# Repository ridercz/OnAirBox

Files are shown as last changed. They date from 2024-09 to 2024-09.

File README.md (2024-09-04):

# OnAirBox

ON-AIR indicator light controlled via MQTT, based on ESP32. In a home with two cats, two children and one wolfdig it's hard to get quiet to shoot video. I made indicator I'm shooting, requesting everyone to be quiet. Let's see if it works at least for the less fluffy part of the pack.

The project is described in the following YouTube video (Czech only):

(https://www.youtube.com/watch?v=Rm-qM90mfA4)

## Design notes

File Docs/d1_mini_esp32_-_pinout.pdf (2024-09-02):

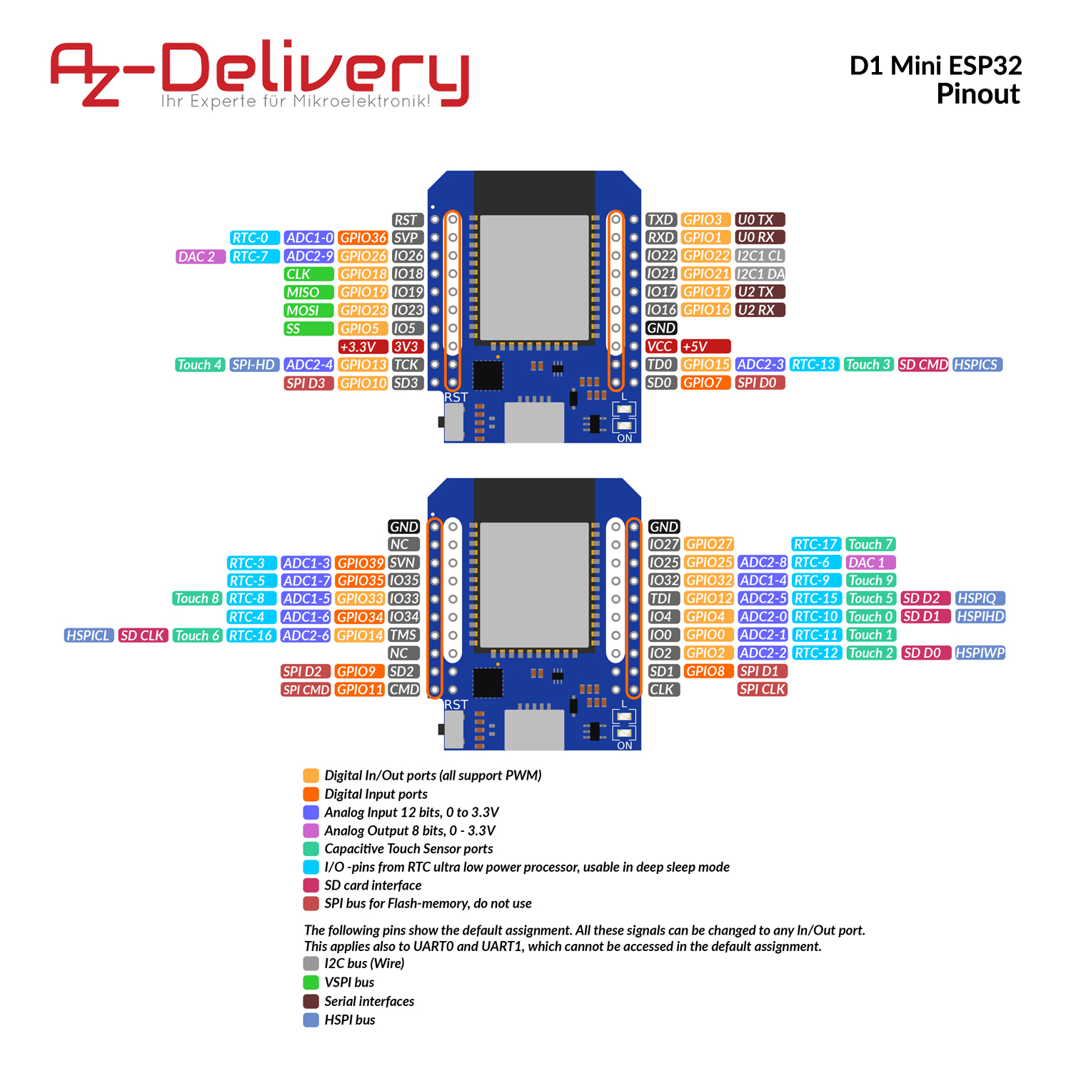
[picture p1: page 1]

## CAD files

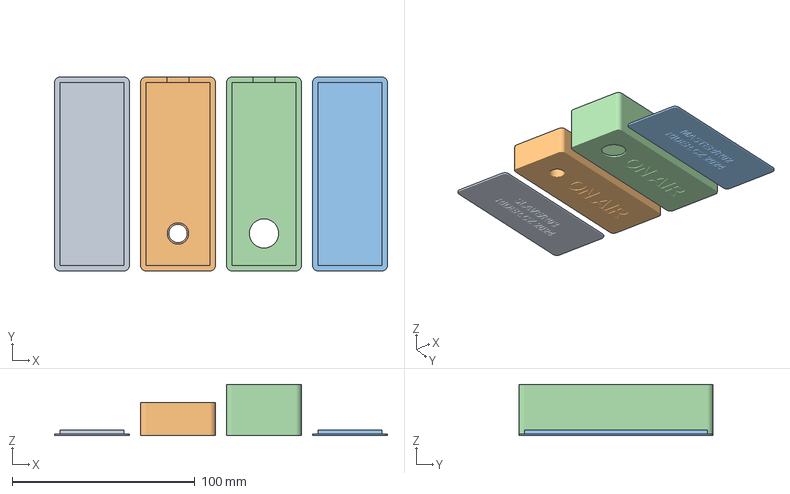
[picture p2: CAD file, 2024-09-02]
Box/OnAirBox-latest.3mf
182.0 x 106.0 x 28.0 mm
OnAirBox-SLAVE-R03.stl_1
OnAirBox-SLAVE-R03.stl_2
OnAirBox-MASTER-R02.stl_1
OnAirBox-MASTER-R02.stl_2

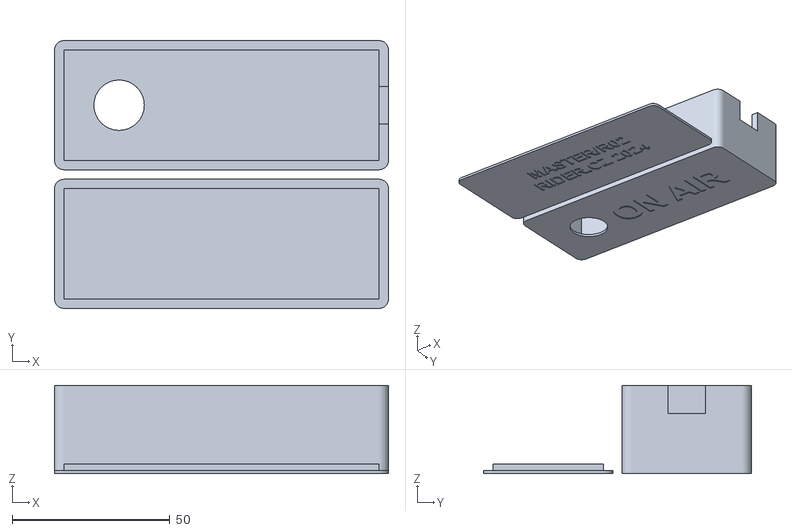
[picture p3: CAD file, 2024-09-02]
Box/OnAirBox-MASTER-R02.stl
106.0 x 85.0 x 28.0

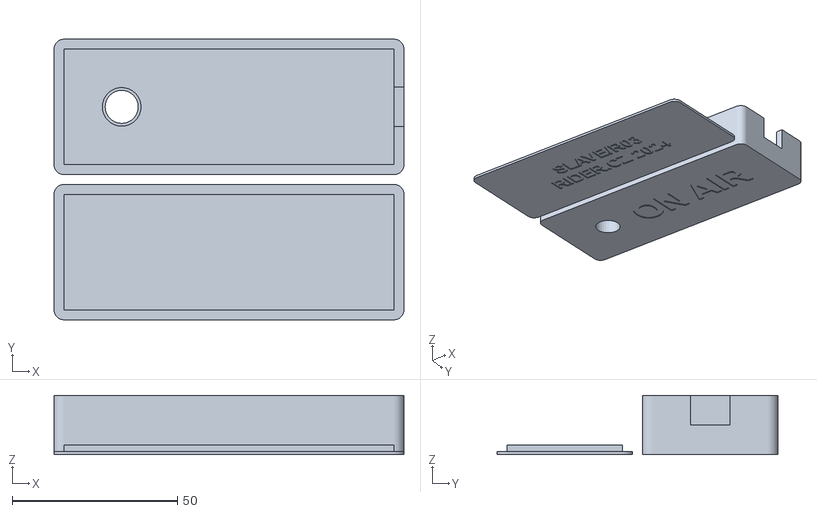
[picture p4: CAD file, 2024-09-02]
Box/OnAirBox-SLAVE-R03.stl
106.0 x 85.0 x 18.0

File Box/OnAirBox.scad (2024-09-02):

/********************************************************************************************************************
 * On-Air Indicator Box                                                                                             *
 * ---------------------------------------------------------------------------------------------------------------- *
 * Copyright (c) Michal Altair Valasek, 2024 | www.rider.cz | github.com/ridercz                                    *
 * Licensed under terms of the Creative Commons Attribution-NonCommercial-ShareAlike 4.0 International License.     *
 * ---------------------------------------------------------------------------------------------------------------- *
 * This is a simple box for an on-air indicator. It has a hole for a LED or a button with LED, a hole for USB       *
 * connector and a text on the front side. The lid is designed to be press-fit to the box.                          *
 ********************************************************************************************************************/

include <A2D.scad>; // https://github.com/ridercz/A2D
assert(a2d_required([1, 6, 2]), "Please upgrade A2D library to version 1.6.2 or higher.");

/* [General] */
main_hole_diameter = 16;
main_hole_lip_thickness  = 0;
main_hole_lip_height = 0;
inner_size = [100, 35, 25];
corner_radius = 3;
face_thickness = 1;
lid_thickness = 2; 

/* [USB connector hole] */
usb_width = 10;
usb_height = 8;
usb_offset_y = 0;

/* [Text] */
text_face_string = "ON AIR";
text_face_size = 12;
text_face_offset = -6;
text_face_font = "Arial:bold";
text_face_extr = .4;
text_lid_string = ["MASTER/R02", "RIDER.CZ 2024"];
text_lid_size = 6;
text_lid_font = "Arial:bold";
text_lid_extr = .4;

/* [Hidden] */
$fudge = 1;
$fn = 32;
outer_size = inner_size + [2 * corner_radius, 2 * corner_radius, 2 * face_thickness + lid_thickness];

echo("Outer size: ", outer_size);

/* Render ***********************************************************************************************************/

translate([0, outer_size.y + 3]) part_box();
part_lid();

/* Parts ************************************************************************************************************/

module part_box() {
    difference() {
        // The box itself
        union() {
            linear_extrude(height = face_thickness) r_square([outer_size.x, outer_size.y], corner_radius);
            linear_extrude(height = outer_size.z - face_thickness) rh_square([outer_size.x, outer_size.y], radius = corner_radius, thickness = -corner_radius);
        }

        // LED or button hole
        translate(v = [outer_size.y / 2, outer_size.y / 2, -$fudge]) cylinder(d = main_hole_diameter, h = face_thickness + 2 * $fudge);

        // USB connector hole
        translate(v = [outer_size.x - corner_radius - $fudge, (outer_size.y - usb_width) / 2 + usb_offset_y, outer_size.z - usb_height - lid_thickness]) cube([corner_radius + 2 * $fudge, usb_width, usb_height + lid_thickness + $fudge]);

        // Text
        translate(v = [outer_size.y + text_face_offset, outer_size.y / 2, -$fudge]) linear_extrude(height = $fudge + text_face_extr) mirror(v = [0, 1, 0]) text(text = text_face_string, size = text_face_size, font = text_face_font, halign = "left", valign = "center");
    }

    // LED lip
    if(main_hole_lip_height > 0 && main_hole_lip_thickness > 0) translate(v = [outer_size.y / 2, outer_size.y / 2]) linear_extrude(height = main_hole_lip_height) h_circle(d = main_hole_diameter, thickness = main_hole_lip_thickness);
}

module part_lid() {
    difference() {
        union() {
            // Bottom part
            linear_extrude(height = face_thickness) r_square([outer_size.x, outer_size.y], corner_radius);

            // Interlocking part
            translate(v = [corner_radius, corner_radius]) cube([inner_size.x, inner_size.y, face_thickness + lid_thickness]);
        }
        // Text
        translate(v = [outer_size.x / 2, outer_size.y / 2, -$fudge]) linear_extrude(height = $fudge + text_lid_extr) mirror(v = [0, 1, 0]) multiline_text(text = text_lid_string, size = text_lid_size, font = text_lid_font, line_height = 1.6, halign = "center", valign = "center");
    }

}

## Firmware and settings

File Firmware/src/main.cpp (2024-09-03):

/********************************************************************************************************************
 * On-Air Indicator Box                                                                                             *
 * ---------------------------------------------------------------------------------------------------------------- *
 * Copyright (c) Michal Altair Valasek, 2024 | www.rider.cz | github.com/ridercz                                    *
 * Licensed under terms of the Creative Commons Attribution-NonCommercial-ShareAlike 4.0 International License.     *
 * ---------------------------------------------------------------------------------------------------------------- *
 * This sketch demonstrates how to create an "ON-AIR" box that can be used to signalize that a person is currently  *
 * streaming or recording using a LED.                                                                              *
 * This firmware is for both MASTER and SLAVE devices:                                                              *
 * - SLAVE devices receive messages from MQTT server and turn their LED on or off accordingly.                      *
 * - MASTER has a locking button in addition. It signalizes the ON-AIR or OFF-AIR status by sending MQTT messages.  *
 * ---------------------------------------------------------------------------------------------------------------- *
 * Wiring:                                                                                                          *
 * - Connect button between pin IO33 and GND (master only).                                                         *
 * - Connect LED between pin IO2 (built-in LED) and GND.                                                            *
 ********************************************************************************************************************/

#define VERSION "OnAirBox/2.1.0"

/* Libraries *******************************************************************************************************/

#include <Arduino.h>
#include <PubSubClient.h>
#include <WiFi.h>
#include <WiFiClientSecure.h>

/* Configuration - change to fit your needs *************************************************************************/

// WiFi connection options
#define WIFI_SSID "boxlab.lazyhorse.net" // WiFi network SSID
#define WIFI_PASS "IHaveHorsePower!"     // WiFi network password

// MQTT connection options
#define MQTT_SERVER "mqtt.boxlab.lazyhorse.net" // MQTT server address
#define MQTT_PORT 8883                          // MQTT server port
#define MQTT_USERNAME ""                        // MQTT username - set to "" if not used
#define MQTT_PASSWORD ""                        // MQTT password - set to "" if not used
#define MQTT_SERVER_TLS                         // Remove if server does not use TLS
#define MQTT_TOPIC_STATUS "onair/status"        // MQTT topic for status change messages
#define MQTT_TOPIC_ARRIVE "onair/arrive"        // MQTT topic for arrival messages (when device connects)
#define MQTT_TOPIC_DEPART "onair/depart"        // MQTT topic for departure messages (when device disconnects)
#define MQTT_RECONNECT_DELAY 30000              // ms; delay between reconnection attempts

/* Internal configuration - do not change unless you know what you are doing *****************************************/

// Operational parameters
#define LED_PIN LED_BUILTIN      // LED pin - use built-in LED
#define LED_INTERVAL 1000        // ms; LED blink interval
#define LED_TTL 30000            // ms; repeat interval for "on air" messages
#define LED_TIMEOUT 70000        // ms; timeout after which the LED is turned off, if no message is received, must be greater than LED_TTL
#define BUTTON_PIN 33            // Button pin
#define BUTTON_DEBOUNCE 50       // ms; button debounce time
#define REBOOT_INTERVAL 97200000 // ms; preventive reboot interval (27 hours)
#define WIFI_TIMEOUT 60000       // ms; device will reboot when it cannot connect to WiFi for this time
#define LOOP_SLEEP 100           // ms; loop sleep time

/* Global variables *************************************************************************************************/
#ifdef MQTT_SERVER_TLS
WiFiClientSecure wifiClient; // WiFi client with TLS
#else
WiFiClient wifiClient; // WiFi client without TLS
#endif
PubSubClient mqttClient(wifiClient);   // MQTT client instance
unsigned long lastMessageReceived = 0; // Last message received millis (used to detect mqtt timeout)
unsigned long lastLedToggle = 0;       // Last LED toggle millis (used to blink LED)
unsigned long lastMessageSent = 0;     // Last message sent millis (used to prevent mqtt timeout)
unsigned long lastWifiConnection = 0;  // Last WiFi connection start millis (used to detect connection timeout)
bool isOnAir = false;                  // On-Air status
bool lastLedState = false;             // Last LED blink state (used to toggle LED)
bool lastButtonState = false;          // Last button press state (used to toggle state)
bool firstWiFiConnection = true;       // First WiFi connection flag
bool firstMqttConnection = true;       // First MQTT connection flag

/* Helper methods ***************************************************************************************************/

// This method ensures that the device is connected to WiFi
void ensureWifiConnected()
{
  // If we are already connected, do nothing
  if (WiFi.status() == WL_CONNECTED)
    return;

  // Turn LED ON
  digitalWrite(LED_PIN, HIGH);

  // Connect to WiFi
  if (firstWiFiConnection)
  {
    Serial.print("Connecting to " WIFI_SSID "...");
  }
  else
  {
    Serial.print("Reconnecting to " WIFI_SSID "...");
  }
  firstWiFiConnection = false;
  WiFi.begin(WIFI_SSID, WIFI_PASS);
  lastWifiConnection = millis();
  while (WiFi.status() != WL_CONNECTED)
  {
    delay(500);
    Serial.print(".");

    // If we cannot connect to WiFi for a long time, reboot
    if (millis() - lastWifiConnection > WIFI_TIMEOUT)
    {
      Serial.println("\nWiFi connection timeout, rebooting...");
      ESP.restart();
    }
  }
  Serial.println("OK");
  Serial.print("IP: ");
  Serial.println(WiFi.localIP().toString());
}

// This method ensures that the device is connected to WiFi and MQTT server
void ensureMqttConnected()
{
  while (mqttClient.state() != MQTT_CONNECTED)
  {
    // First, ensure we are connected to WiFi
    ensureWifiConnected();

    // Turn LED on
    digitalWrite(LED_PIN, HIGH);

    // If it's not first connection attempt, print the current state and wait for a while
    if (!firstMqttConnection)
    {
      switch (mqttClient.state())
      {
      case MQTT_CONNECTION_TIMEOUT:
        Serial.println("MQTT connection state: timeout (server didn't respond)");
        break;
      case MQTT_CONNECTION_LOST:
        Serial.println("MQTT connection state: connection lost (server disconnected)");
        break;
      case MQTT_CONNECT_FAILED:
        Serial.println("MQTT connection state: connection failed (server didn't accept the connection)");
        break;
      case MQTT_DISCONNECTED:
        Serial.println("MQTT connection state: disconnected");
        break;
      case MQTT_CONNECT_BAD_PROTOCOL:
        Serial.println("MQTT connection state: bad protocol (unsupoorted version)");
        break;
      case MQTT_CONNECT_BAD_CLIENT_ID:
        Serial.println("MQTT connection state: bad client ID (server rejected client ID)");
        break;
      case MQTT_CONNECT_UNAVAILABLE:
        Serial.println("MQTT connection state: unavailable (server was unable to accept connection)");
        break;
      case MQTT_CONNECT_BAD_CREDENTIALS:
        Serial.println("MQTT connection state: bad credentials");
        break;
      case MQTT_CONNECT_UNAUTHORIZED:
        Serial.println("MQTT connection state: unauthorized");
        break;
      default:
        Serial.printf("MQTT connection state: %d (unknown)\n", mqttClient.state());
        break;
      }
      Serial.printf("Waiting %d ms before next connection attempt...\n", MQTT_RECONNECT_DELAY);
      delay(MQTT_RECONNECT_DELAY);
    }
    firstMqttConnection = false;

    // Connect to MQTT server
    Serial.printf("Connecting to %s:%d...", MQTT_SERVER, MQTT_PORT);
    auto clientId = WiFi.macAddress();
    mqttClient.setServer(MQTT_SERVER, MQTT_PORT);
    if (mqttClient.connect(clientId.c_str(), MQTT_USERNAME, MQTT_PASSWORD, MQTT_TOPIC_DEPART, 0, false, clientId.c_str()))
    {
      Serial.println("OK");

      // Send a message that we have arrived
      Serial.printf("Publishing to topic %s...", MQTT_TOPIC_ARRIVE);
      if (mqttClient.publish(MQTT_TOPIC_ARRIVE, clientId.c_str()))
      {
        Serial.println("OK");
      }
      else
      {
        Serial.println("Failed!");
      }

      // Subscribe to chat topic
      Serial.printf("Subscribing to topic %s...", MQTT_TOPIC_STATUS);
      if (mqttClient.subscribe(MQTT_TOPIC_STATUS))
      {
        Serial.println("OK");
      }
      else
      {
        Serial.println("Failed!");
      }
    }
    else
    {
      // Connection failed
      Serial.println("Failed!");
    }
  }
}

// This method is called when a message is received from MQTT
void mqttCallback(char *topic, byte *payload, unsigned int length)
{
  // Process message
  if (length == 1 && payload[0] == '1')
  {
    isOnAir = true;
    lastMessageReceived = millis();
    Serial.printf("On-Air status set to ON for %i ms\n", LED_TIMEOUT);
  }
  else if (length == 1 && payload[0] == '0')
  {
    isOnAir = false;
    lastMessageReceived = millis();
    Serial.println("On-Air status set to OFF");
  }
  else
  {
    // Print received message
    Serial.printf("Unrecognized message arrived to topic %s, lenght %i bytes: ", topic, length);
    for (int i = 0; i < length; i++)
    {
      Serial.print((char)payload[i]);
    }
    Serial.println();
  }
}

/* Main program *****************************************************************************************************/

// This method is called once at the beginning of the program
void setup()
{
  // Initialize serial port
  Serial.begin(9600);
  delay(500);
  Serial.println();
  Serial.println();
#ifdef BUTTON_PIN
  Serial.println(VERSION " (master configuration)");
#else
  Serial.println(VERSION " (slave configuration)");
#endif

  // Initialize LED pin and turn LED ON
  pinMode(LED_PIN, OUTPUT);
  digitalWrite(LED_PIN, HIGH);

#ifdef BUTTON_PIN
  // Initialize button pin, if defined
  pinMode(BUTTON_PIN, INPUT_PULLUP);
  // Set last button state to inverse of current state to force initial state change
  lastButtonState = !digitalRead(BUTTON_PIN);
#endif

#ifdef MQTT_SERVER_TLS
  // Disable TLS server certificate verification
  wifiClient.setInsecure();
#endif

  // Set MQTT client callback
  mqttClient.setCallback(mqttCallback);
}

// This method is called repeatedly in an endless loop
void loop()
{
#ifdef REBOOT_INTERVAL
  // Reboot every REBOOT_INTERVAL ms if defined, unless currently on air
  if (!isOnAir && millis() > REBOOT_INTERVAL)
  {
    Serial.println("Rebooting...");
    ESP.restart();
  }
#endif

  // Ensure MQTT connection
  ensureMqttConnected();

#ifdef BUTTON_PIN
  // Check for button state, if defined
  bool currentButtonState = digitalRead(BUTTON_PIN);
  if (currentButtonState != lastButtonState)
  {
    // This is very crude debouncing, but it works for our purposes
    delay(BUTTON_DEBOUNCE);
    if (currentButtonState == digitalRead(BUTTON_PIN))
    {
      lastButtonState = currentButtonState;
      if (currentButtonState == LOW)
      {
        Serial.print("Button pressed, enabling ON AIR mode...");
        bool result = mqttClient.publish(MQTT_TOPIC_STATUS, "1");
        lastMessageSent = millis();
        Serial.println(result ? "OK" : "Failed!");
      }
      else
      {
        Serial.print("Button released, disabling ON AIR mode...");
        bool result = mqttClient.publish(MQTT_TOPIC_STATUS, "0");
        Serial.println(result ? "OK" : "Failed!");
      }
    }
  }

  // Send message every LED_TTL ms
  if (isOnAir && millis() - lastMessageSent > LED_TTL)
  {
    Serial.print("Sending ON AIR message before TTL...");
    bool result = mqttClient.publish(MQTT_TOPIC_STATUS, "1");
    lastMessageSent = millis();
    Serial.println(result ? "OK" : "Failed!");
  }
#endif

  // Handle MQTT messages
  mqttClient.loop();

  if (isOnAir && millis() - lastMessageReceived > LED_TIMEOUT)
  {
    isOnAir = false;
    Serial.println("On-Air status set to OFF (timeout)");
  }

  // Check for on-air status
  if (isOnAir)
  {
    if (LED_INTERVAL == 0)
    {
      // Turn on LED
      digitalWrite(LED_PIN, HIGH);
    }
    else if (millis() - lastLedToggle > LED_INTERVAL)
    {
      // Blink LED
      lastLedToggle = millis();
      lastLedState = !lastLedState;
      digitalWrite(LED_PIN, lastLedState ? HIGH : LOW);
    }
  }
  else
  {
    // Turn off LED
    digitalWrite(LED_PIN, LOW);
  }

#ifdef LOOP_SLEEP
  // Sleep for a while
  delay(LOOP_SLEEP);
#endif
}

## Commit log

2024-09-02 Add PrusaSlicer project for 3D printing.
    [OnAirBox-latest.3mf]
2024-09-02 Upload Wemos D1 Mini ESP32 pinout diagram
2024-09-03 - Add some comments - Do not call setInsecure() if no TLS is used - Fix formatting of WiFi connection message
    [main.cpp]
